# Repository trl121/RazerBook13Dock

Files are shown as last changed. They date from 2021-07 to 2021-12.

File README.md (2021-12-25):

# Razer Book13 Dock

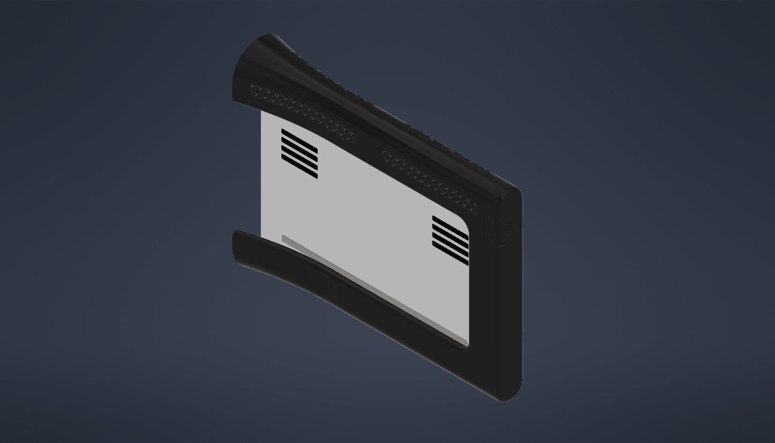
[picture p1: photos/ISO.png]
ISO View


<br/>
<br/>

## Description
This is a 3D printable laptop dock for a Razer Book 13. This laptop dick essentially a sleeve that a Razer Book 13 laptop will slide into allowing it to connect to various IO. In this version of the dock, only 1 USB C/Thunderbolt 4 cable was used for power, display, USB devices, and networking. This cable was connected to the dock via epoxy and clamp. This clamp and the cutout in the dock for the for the cable, can be seen in Figures 1 and 2.  

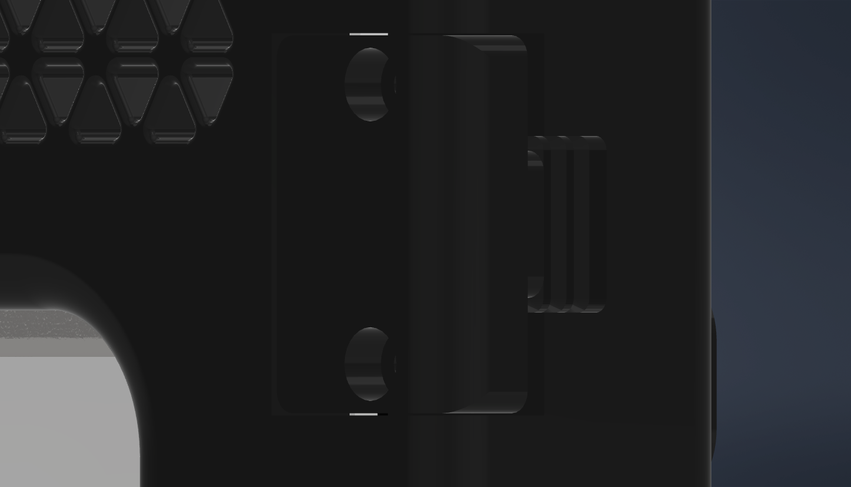
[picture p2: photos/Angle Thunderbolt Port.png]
Angle View of Thunderbolt Port

<p style="text-align: center;">Figure 1, Angle View of USB C Clamp</p>
<br/>

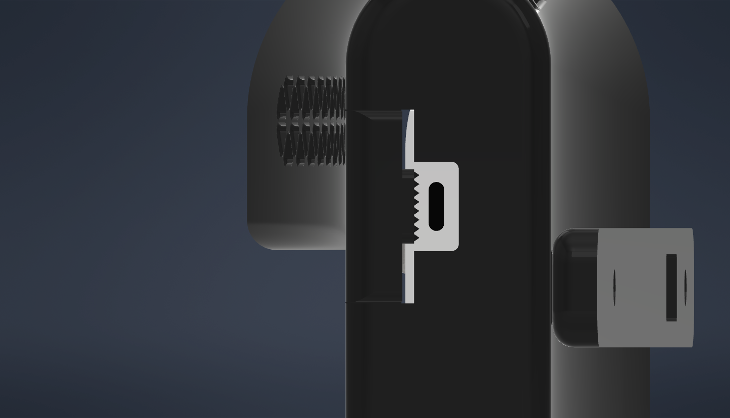
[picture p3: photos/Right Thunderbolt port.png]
Straight View of Thunderbolt Port

<p style="text-align: center;">Figure 2, Straight View of USB C Clamp</p>
<br/>

<br/>

The Razer Book 13 is inserted into the dock via a funneling mechanism incorparated into the shape of the dock. This funneling mechanism can be seen in Figure 3.

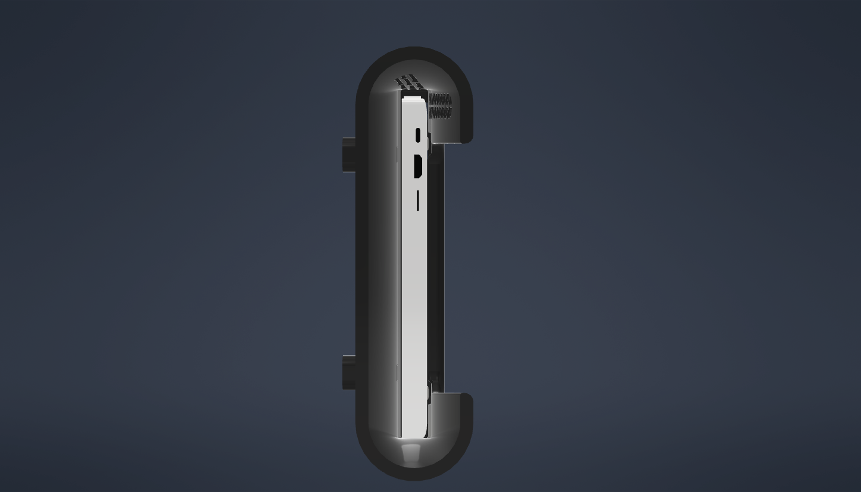
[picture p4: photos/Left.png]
Funnel View of Dock

<p style="text-align: center;">Figure 3, Funnel View of Laptop Dock</p>
<br/>

<br/>

This laptop dock is composed 5 3D printable parts as seen in Figure 4 and the list below.
- 1x Upper Part → Funnel Part of the Dock
- 1x Bottom Part → Base Part of the Dock
- 2x Mount → Screw to a surface and contain dovetails to allow the upper and bottom parts to slide into the mounts
- 1x USB C Clamp → Clamp to secure the USB Cable once epoxied in place. 

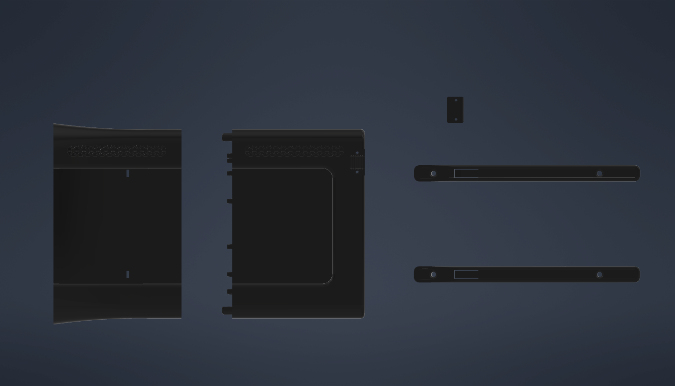
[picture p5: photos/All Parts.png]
All Parts View

<p style="text-align: center;">Figure 4, All Parts</p>
<br/>

<br/>

The upper and lower parts connect via printed snap clips. These two clips are unidirectional clips so once they are joined then can not be easily separated. The joined upper and bottom parts slide into the mounts and lock in place via unidirectional snap clips. To allow the dock to be removable, there are slots in the upper part where the snap clips on the mounts can be pushed out of the way to remove the joined upper and bottom part from the mounts. The USB C Clamp is connected to the bottom part via two heat set inserts and two 3mm screws. The bottom part has through holes for the 3mm screws, and channels for the heat set inserts on the top of these through holes.

<br/>
<br/>

## Printing Details

I printed these part on a modified Ender 3. The Toleances for the mates of these parts is about 0.2mm. 

I printed these parts with the follwing settings:
- material: Inland Black PETG
- layer height: 2.4mm
- Infill: Gyroid 10%
- Perimeters: 3
- Top solid layers: 7
- Bottom solid Layers: 7
- Supports: Where specified

<br/>
<br/>

## Slicing Details

### Upper Part

This part printed vertically with the funnel end down. No supports were added to this part.

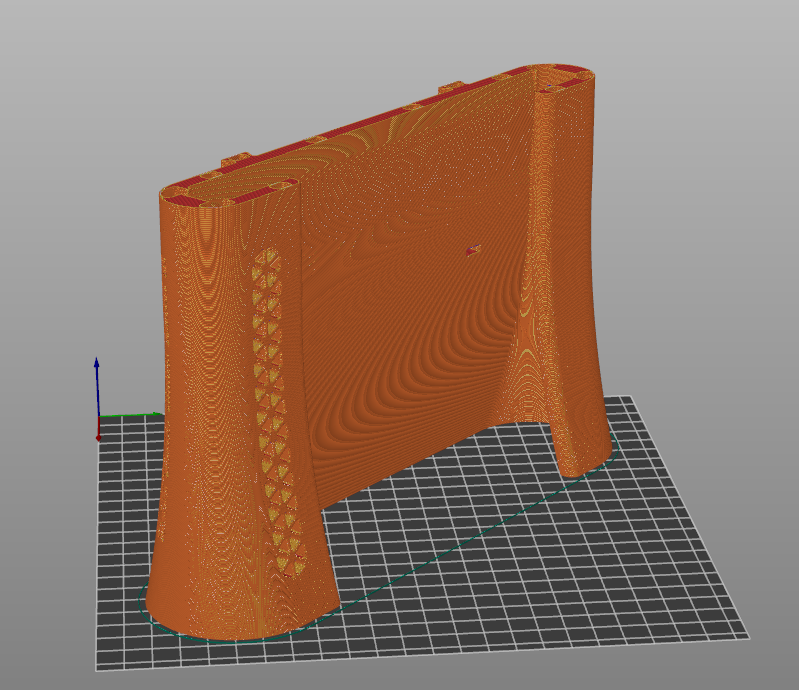
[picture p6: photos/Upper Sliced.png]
Upper Part Sliced


<br/>

### Bottom Part

This part was printed vertically with the closed end down. Supports were added to the overhang for the clamp and upper snaps.

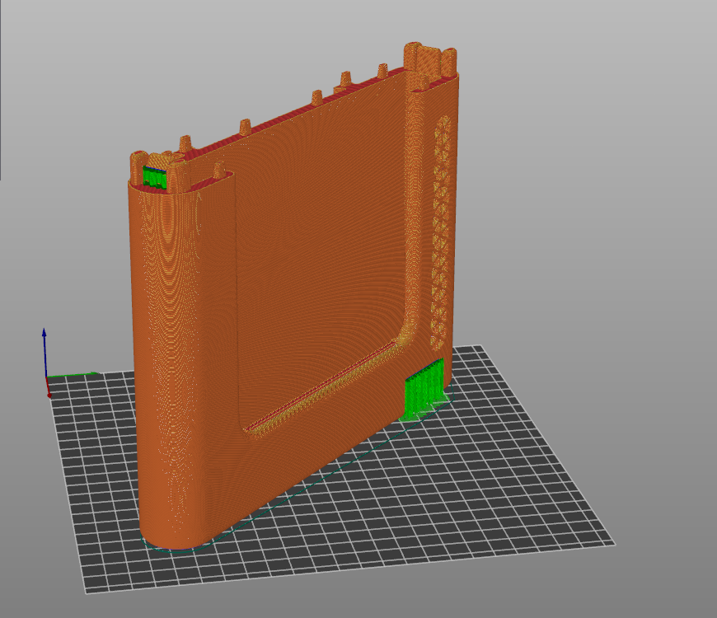
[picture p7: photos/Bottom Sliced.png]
Bottom Part Sliced


<br/>

### Mounts

This part was printed flat with the wall mount side down. To fit on the ender 3 this part rotated 45° along the z axis. Supports were added under the mount snaps.

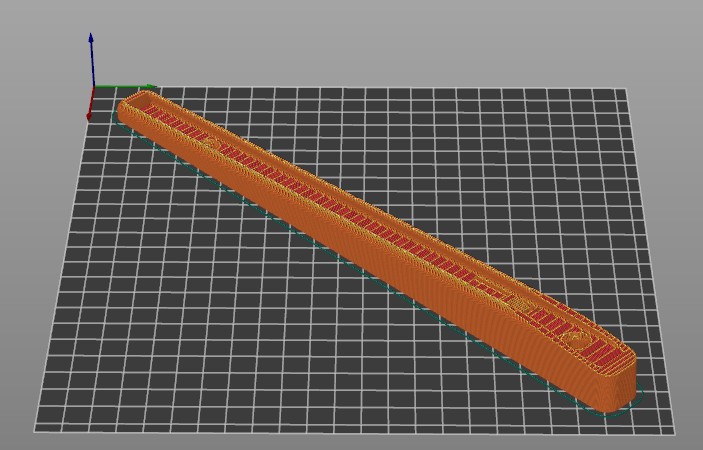
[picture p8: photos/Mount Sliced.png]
Mount Part Sliced


<br/>

### Clamp

The clamp was printed flat with the inside spiny texture pointing up.

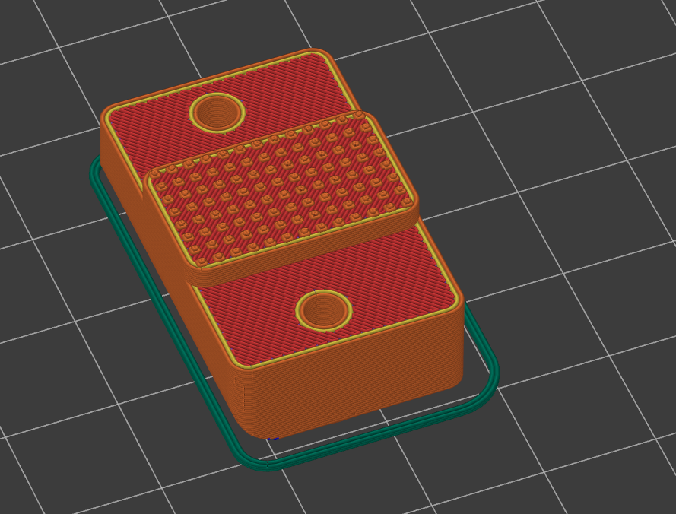
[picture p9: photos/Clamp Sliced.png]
Clamp Part Sliced


<br/>
<br/>

## Cleanup 

These parts required very little clean asside from removing the supports. All supports were fully removed excexpt for the supports for the snaps on the bottom parts. These supports were sufficently removed to to prevent interferace but the rest of the supports were keep in place due to the small working area and somewhat fragile snap. A few other areas were filed down where need to allow for proper fits.

<br/>
<br/>

## Warnings

I made this dock for a friend and did not have the laptop on hand. I had to guess the position the ports on the laptop based on pictures I found on the internet. I refined the positon of the thunderbolt 4 port that was used based on printing test peices for the bottom. The rest of the ports on the given Razer Book 13 CAD model are likely in the wrong spot. 

The snaps between the upper and bottom parts can be fragile due to there printed orientaion. Due to their size and a few test prints I didn't have a problem with this. However, on the final print I did for this project one of the snaps broke. Upon removing the snap there is sufficient room to weld the parts together with a soldering iron and plastic from failed prints. 

<br/>
<br/>

## Software Details

3D CAD Software - Inventor 2021  
Slicing Software - Prusa Slicer

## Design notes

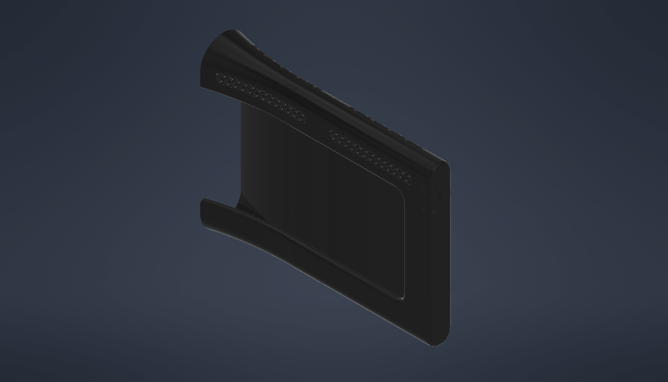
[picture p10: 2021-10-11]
photos/ISO No Laptop.png

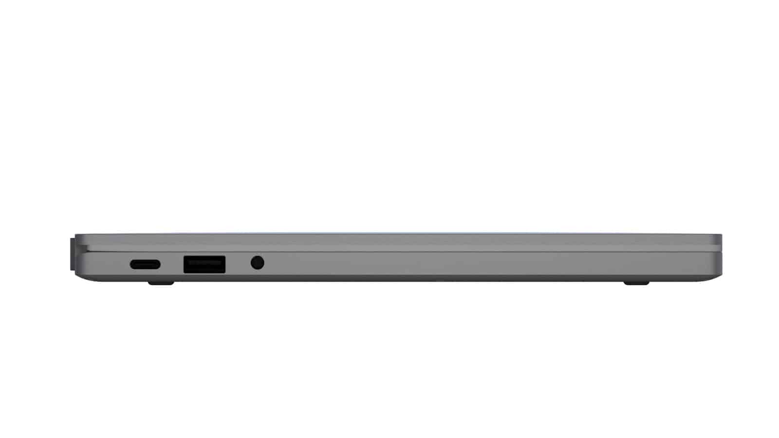
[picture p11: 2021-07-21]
Inventor/_Photos/Side View.jpg

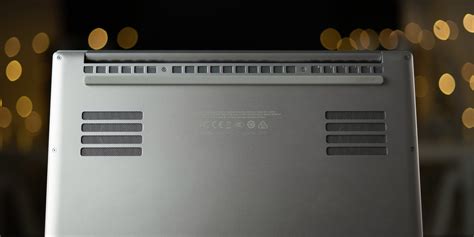
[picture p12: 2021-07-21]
Inventor/_Photos/Bottom.jpg

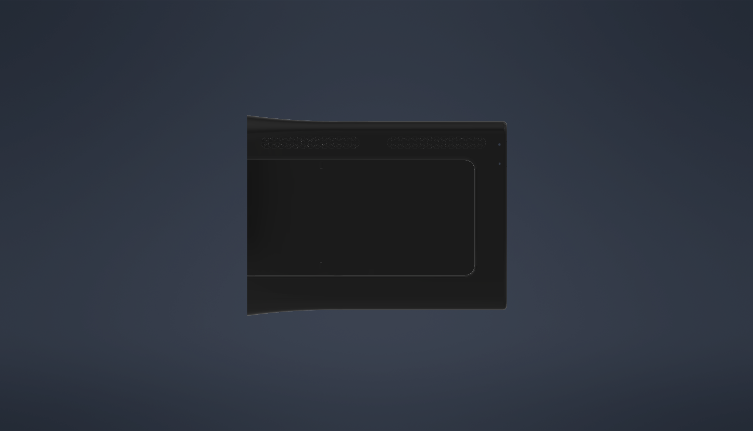
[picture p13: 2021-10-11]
photos/Front.png

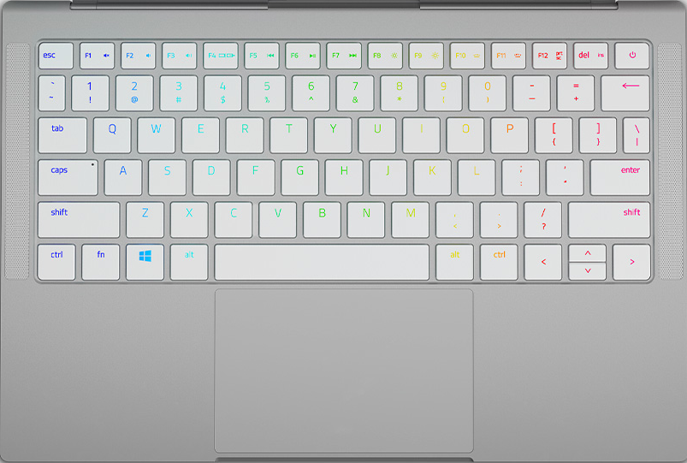
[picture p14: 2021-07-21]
Inventor/_Photos/topCropped.png

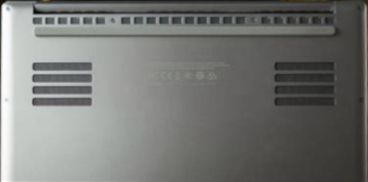
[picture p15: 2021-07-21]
Inventor/_Photos/Bottom.png

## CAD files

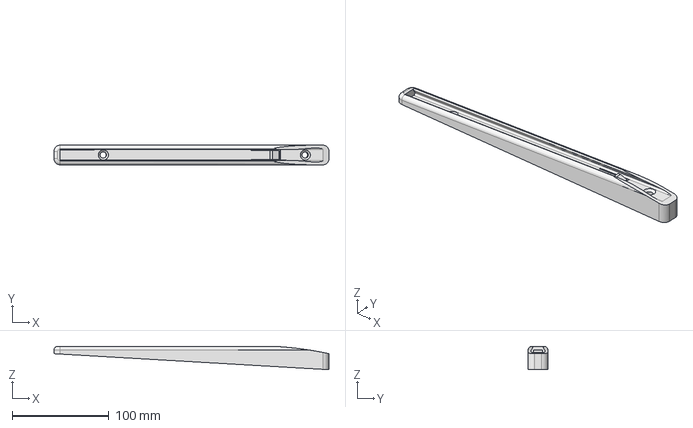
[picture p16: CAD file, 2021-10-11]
STEP/Mount_.stp
283.8 x 20.3 x 24.1 mm

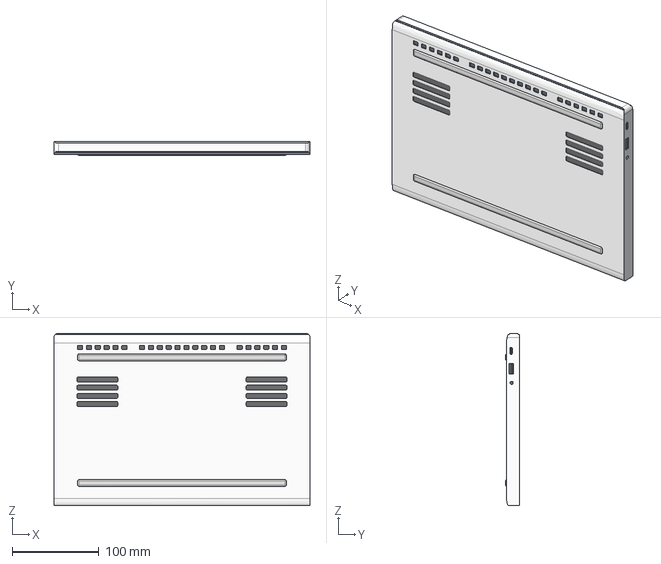
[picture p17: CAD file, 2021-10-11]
STEP/Razor Book 13.stp
295.6 x 15.8 x 199.2 mm

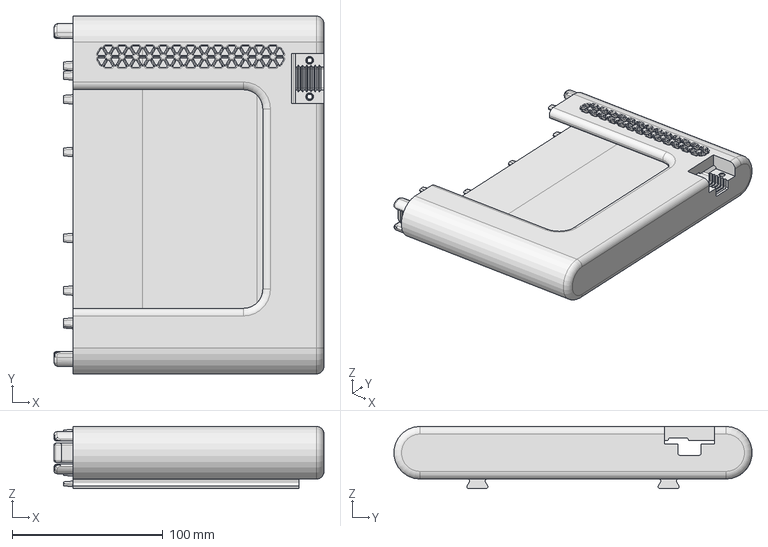
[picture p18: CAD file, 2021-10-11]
STEP/BottomPart.stp
179.3 x 237.7 x 41.4 mm

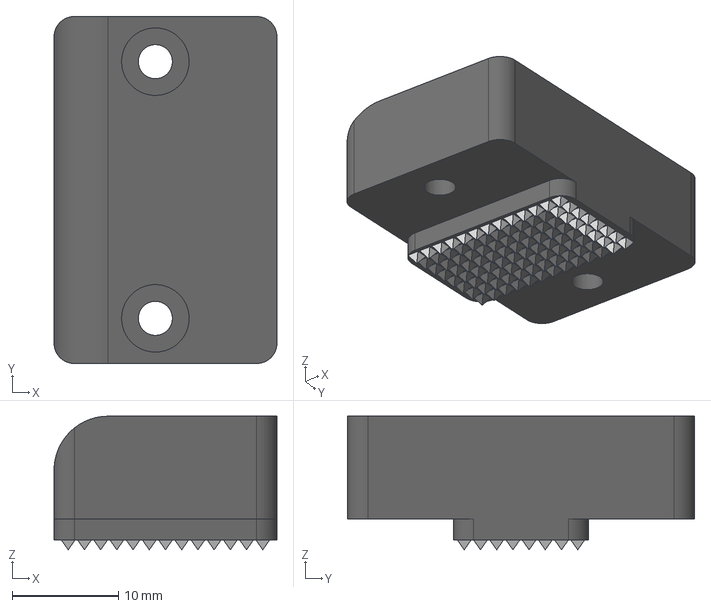
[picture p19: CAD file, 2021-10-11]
STEP/USBCClamp.stp
21.0 x 32.6 x 12.6 mm

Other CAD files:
Inventor/DrillingTemplate.dwg
Inventor/BottomPart.ipt
Inventor/MainAssembly.iam
Inventor/MainAssembly.ipn
Inventor/Razor Book 13.ipt
Inventor/USBCClamp.ipt
STL/Mount_.stl
STL/USBCClamp.stl

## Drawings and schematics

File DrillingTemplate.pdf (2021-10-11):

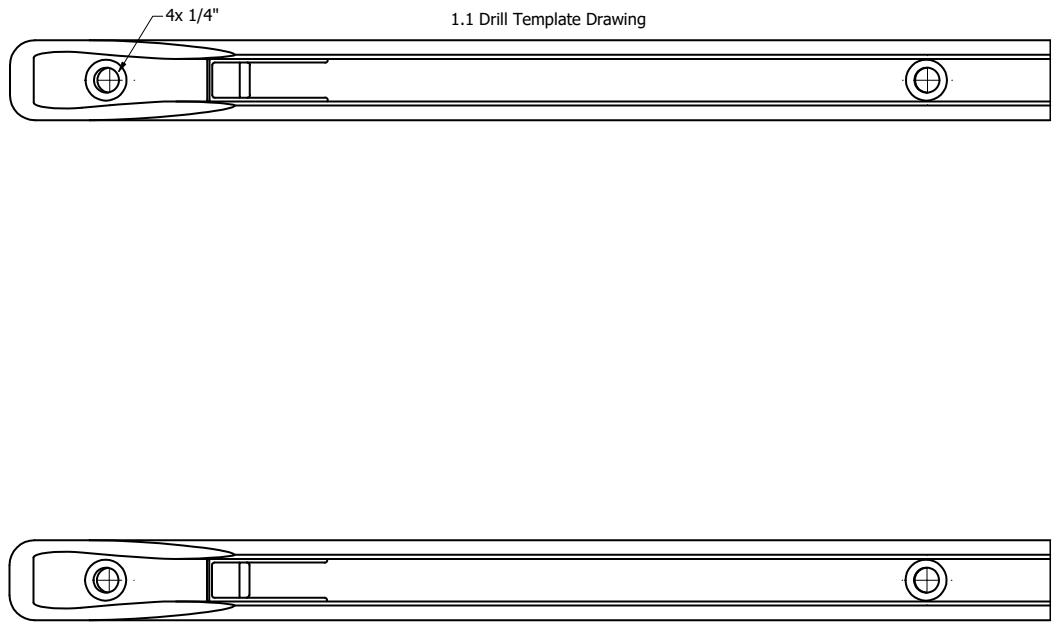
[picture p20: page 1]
1.1 Drill Template Drawing

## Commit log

2021-07-21 Prototype 1.0
    [Bottom Part.ipt, Bottom Part.stl, Main Assembly Without Laptop.stl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]
2021-08-31 Full Prototype 1
    [Bottom Part.ipt, Bottom Part.stl, Main Assembly Without Laptop.stl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]
2021-10-11 First Revision
    [Bottom Part.ipt, BottomPart.ipt, BottomPart.stp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]
